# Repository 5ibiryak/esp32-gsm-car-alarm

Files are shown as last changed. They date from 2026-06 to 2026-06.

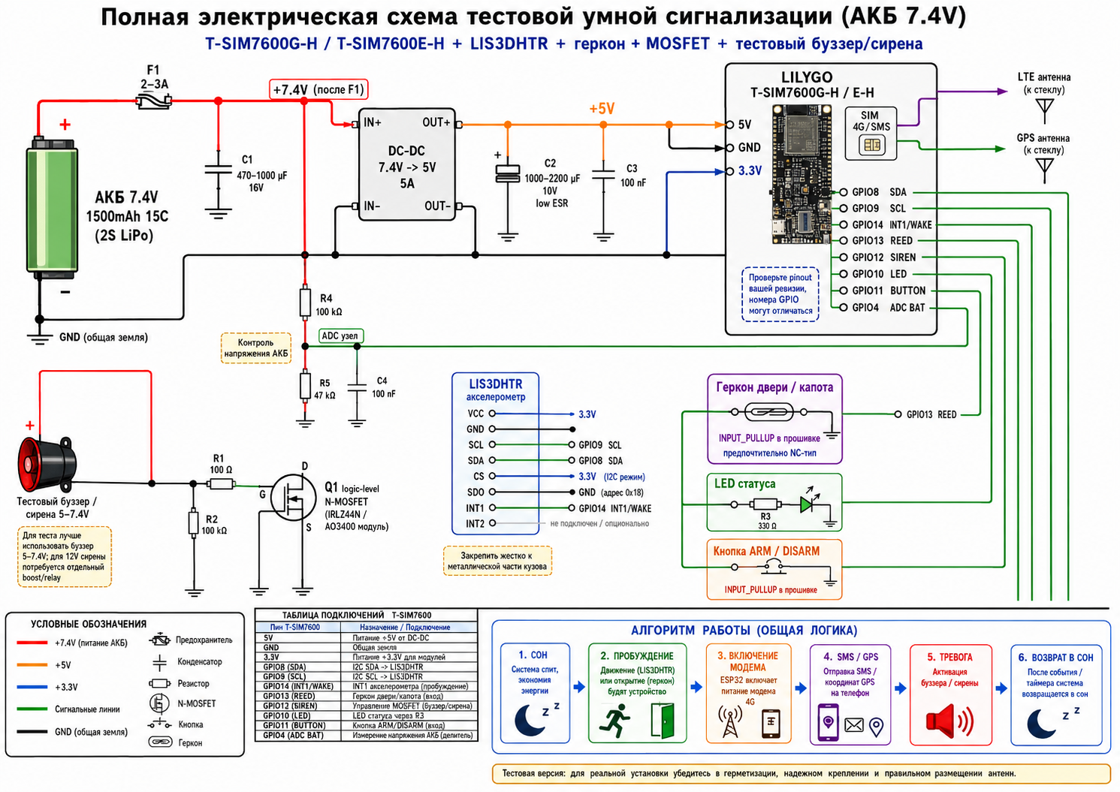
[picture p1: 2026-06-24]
image/ChatGPT Image 24 мая 2026 г., 12_21_52.png

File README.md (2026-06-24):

# ESP32 GSM Car Alarm

Autonomous GSM/GPS car alarm system for Moskvich 412 based on ESP32 and the LILYGO T-SIM7600G-H module.

## Description

This project is an autonomous GSM/GPS car alarm system designed for a Moskvich 412. It is based on an ESP32 board with the LILYGO T-SIM7600G-H module.

The system is installed inside the car and detects shocks, vibration, door/hood opening and other security events. When an alarm is triggered, the device can activate a siren and send SMS notifications to the owner.

The alarm is already installed in the car and is being tested in real conditions.

## Features

* Shock and vibration detection using MPU6050;
* reed switch input for door/hood detection;
* siren control through a MOSFET;
* status LED indicator;
* SMS notifications using SIM7600;
* GPS location support;
* adjustable sensitivity and runtime parameters;
* OTA/web configuration support;
* 3D-printable mounts for the sensor and LED indicator.

## Hardware

Main components:

* LILYGO T-SIM7600G-H / ESP32-WROVER;
* MPU6050 accelerometer;
* SIM7600 GSM/GPS modem;
* reed switch;
* siren;
* MOSFET for siren control;
* external battery;
* 3D-printed enclosure and mounting parts.

## Pinout

| Function | GPIO |
| --- | -----: |
| I2C SDA | GPIO21 |
| I2C SCL | GPIO22 |
| MPU6050 INT | GPIO14 |
| Reed switch | GPIO13 |
| Siren | GPIO32 |
| Status LED | GPIO19 |
| BAT ADC | GPIO35 |
| SIM7600 TX | GPIO27 |
| SIM7600 RX | GPIO26 |
| SIM7600 PWRKEY |  GPIO4 |
| SIM7600 DTR | GPIO25 |

## Project Structure

```text
.
├── include/                 # Header files
├── src/                     # Main firmware source code
├── platformio.ini           # PlatformIO build configuration
├── partitions_ota.csv       # OTA partition table
├── README.md
├── moskvich_alarm_3d.html   # 3D project visualization
├── mpu6050_car_body_mount.stl
├── led_window_holder_5mm.stl
└── images/                  # Wiring diagrams, renders and reference images
```

## Build and Upload

The project is built using PlatformIO.

Build:

```bash
pio run
```

Upload firmware:

```bash
pio run -t upload
```

Serial monitor:

```bash
pio device monitor
```

## 3D Models

The repository includes STL files:

* `mpu6050_car_body_mount.stl` — MPU6050 mount for attaching the sensor to the car body;
* `led_window_holder_5mm.stl` — 5 mm LED holder for placing the status indicator near the window.

## Images and Diagrams

The repository contains wiring diagrams, board reference images and project visualizations.

Recommended structure:

```text
images/
├── wiring-diagram.png
├── 3d-preview.png
└── lilygo-pinout.jpg
```

## Project Status

The project is under active development and real-world testing.

Current status:

* installed in the car;
* basic alarm logic is working;
* SMS notifications are working;
* MPU6050 sensitivity tuning is in progress;
* enclosure, mounting parts and power circuit are being improved.

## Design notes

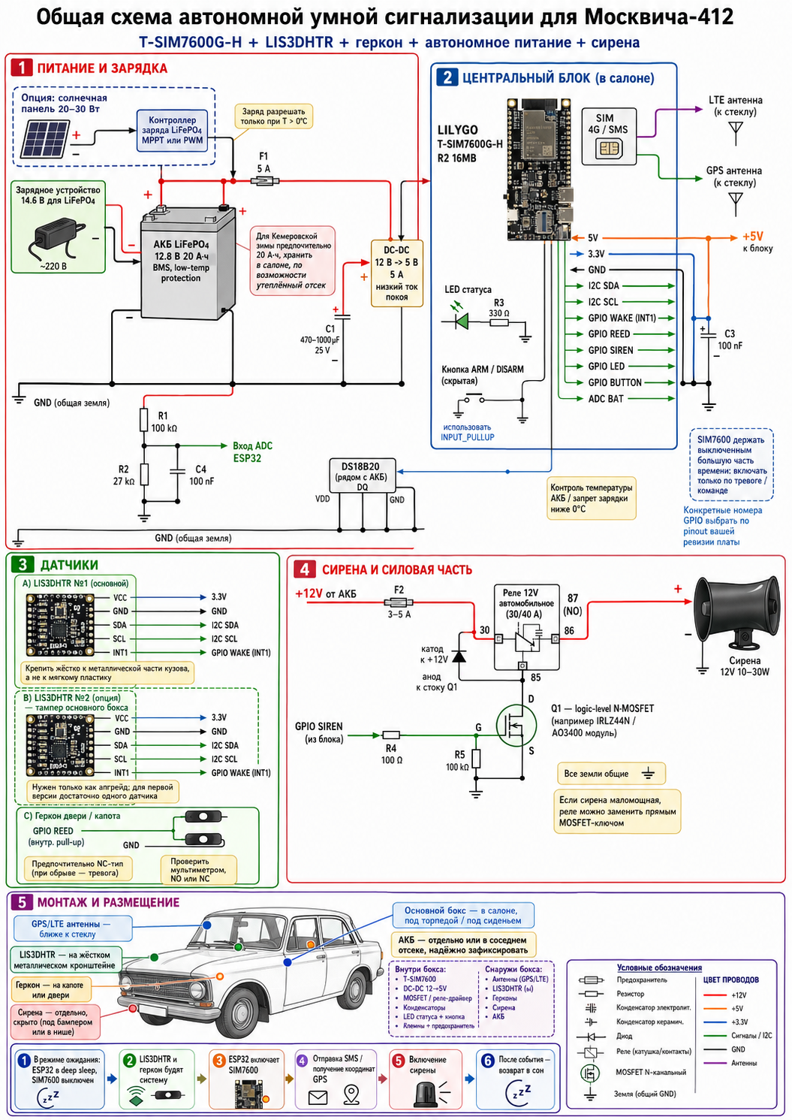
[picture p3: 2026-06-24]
image/Примерная схема сигнализации.png

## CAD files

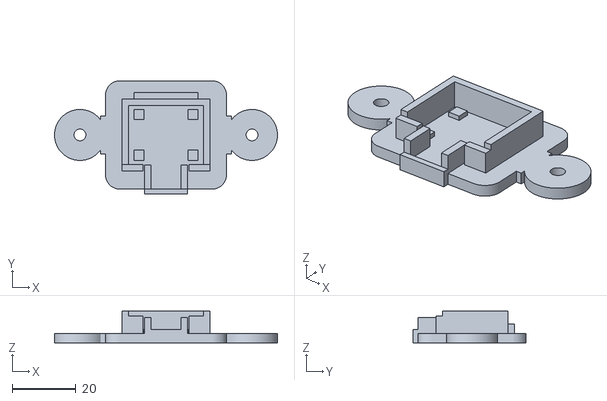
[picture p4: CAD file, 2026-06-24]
3d model/mpu6050_car_body_mount.stl
70.0 x 35.6 x 10.0

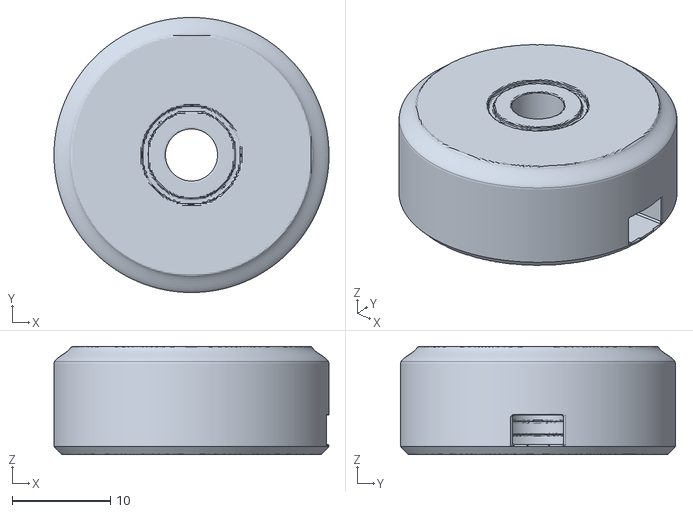
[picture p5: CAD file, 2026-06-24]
3d model/led_window_holder_5mm.stl
28.0 x 28.0 x 11.0

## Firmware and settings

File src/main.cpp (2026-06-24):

#include <Arduino.h>
#include "config.h"

#if WATCHDOG_ENABLED
#include <esp_task_wdt.h>
#endif
#include <esp_system.h>

#include "BatteryMonitor.h"
#include "Accelerometer.h"
#include "ReedSensor.h"
#include "Siren.h"
#include "StatusLed.h"
#include "Button.h"
#include "Modem.h"
#include "RecipientManager.h"
#include "OtaManager.h"
#include "AlarmStateMachine.h"
#include "RuntimeConfig.h"

static BatteryMonitor    battery;
static Accelerometer     accel;
static ReedSensor        reed;
static Siren             siren;
static StatusLed         led;
static Button            button;
static Modem             modem;
static RecipientManager  recipients;
static OtaManager        ota;
static AlarmStateMachine fsm;

static void printBanner() {
    Serial.println();
    Serial.println(F("======================================================"));
    Serial.print  (F("  ")); Serial.print(FW_NAME);
    Serial.print  (F("  v")); Serial.println(FW_VERSION);
    Serial.print  (F("  build: ")); Serial.println(FW_BUILD);
    Serial.println(F("  target: LILYGO T-SIM7600G-H (ESP32-WROVER)"));
    Serial.println(F("======================================================"));
}

static void printPinMap() {
    Serial.println(F("[PINS] --- external peripherals ---"));
    Serial.print(F("  I2C SDA       = GPIO")); Serial.println(PIN_I2C_SDA);
    Serial.print(F("  I2C SCL       = GPIO")); Serial.println(PIN_I2C_SCL);
    Serial.print(F("  ACCEL_INT     = GPIO")); Serial.println(PIN_ACCEL_INT);
    Serial.print(F("  REED          = GPIO")); Serial.println(PIN_REED);
    Serial.print(F("  SIREN         = GPIO")); Serial.println(PIN_SIREN);
    Serial.print(F("  STATUS_LED    = GPIO")); Serial.println(PIN_STATUS_LED);
    Serial.print(F("  BUTTON        = GPIO")); Serial.print(PIN_BUTTON);
    Serial.println(F(" (unused — physical power switch disarms)"));
    Serial.print(F("  BAT_ADC       = GPIO")); Serial.println(PIN_BAT_ADC);

    Serial.println(F("[PINS] --- SIM7600 modem (LILYGO defaults, do not change) ---"));
    Serial.print(F("  MODEM_TX      = GPIO")); Serial.println(MODEM_PIN_TX);
    Serial.print(F("  MODEM_RX      = GPIO")); Serial.println(MODEM_PIN_RX);
    Serial.print(F("  MODEM_PWRKEY  = GPIO")); Serial.println(MODEM_PIN_PWRKEY);
    Serial.print(F("  MODEM_DTR     = GPIO")); Serial.println(MODEM_PIN_DTR);
    Serial.print(F("  MODEM_BAUD    = "));     Serial.println(MODEM_UART_BAUD);
}

#if DEBUG_I2C_LINE_TEST
// Drives GPIO21 / GPIO22 directly so you can verify with a multimeter
// that the signals reach the sensor's SDA / SCL pads.
//
// LOW phase  -> pinMode(OUTPUT_OPEN_DRAIN) + digitalWrite(LOW)  : active pull-down
// RELEASED   -> digitalWrite(HIGH) + pinMode(INPUT_PULLUP)      : ESP32 internal
//               ~45kΩ pull-up plus any module pull-up bring the line to 3.3V
//
// We need INPUT_PULLUP on release because OUTPUT_OPEN_DRAIN with the pin
// driven HIGH still leaves the line floating if no external pull-up is
// fitted — which is what was happening here (lines sat near 0V).
// Loops forever — power-cycle or reset to exit.
static void releaseLine(uint8_t pin) {
    digitalWrite(pin, HIGH);
    pinMode(pin, INPUT_PULLUP);
}
static void pullLineLow(uint8_t pin) {
    pinMode(pin, OUTPUT_OPEN_DRAIN);
    digitalWrite(pin, LOW);
}

static void runI2cLineTest() {
    Serial.println(F("[I2C-LINE] testing GPIO21/GPIO22 physical wiring"));

    releaseLine(21);
    releaseLine(22);

    for (;;) {
        // Phase A: SDA (GPIO21) actively pulled low, SCL released high.
        Serial.println(F("[I2C-LINE] GPIO21 LOW: measure SDA"));
        pullLineLow(21);
        releaseLine(22);
        delay(10000);

        // Phase B: SDA released high, SCL (GPIO22) actively pulled low.
        Serial.println(F("[I2C-LINE] GPIO22 LOW: measure SCL"));
        releaseLine(21);
        pullLineLow(22);
        delay(10000);

        // Phase C: both released to INPUT_PULLUP — both should read ~3.3 V.
        Serial.println(F("[I2C-LINE] RELEASED: both pins INPUT_PULLUP, measure SDA/SCL"));
        releaseLine(21);
        releaseLine(22);
        delay(10000);
    }
}
#endif

static const char* resetReasonName(esp_reset_reason_t r) {
    switch (r) {
        case ESP_RST_POWERON:    return "POWERON";
        case ESP_RST_EXT:        return "EXT";
        case ESP_RST_SW:         return "SW";
        case ESP_RST_PANIC:      return "PANIC";
        case ESP_RST_INT_WDT:    return "INT_WDT";
        case ESP_RST_TASK_WDT:   return "TASK_WDT";
        case ESP_RST_WDT:        return "WDT";
        case ESP_RST_DEEPSLEEP:  return "DEEPSLEEP";
        case ESP_RST_BROWNOUT:   return "BROWNOUT";
        case ESP_RST_SDIO:       return "SDIO";
        default:                 return "UNKNOWN";
    }
}

void setup() {
    Serial.begin(115200);
    delay(200);   // let the host USB enumerate before banner

    const esp_reset_reason_t resetReason = esp_reset_reason();
    Serial.print  (F("[BOOT] reset reason: "));
    Serial.println(resetReasonName(resetReason));
    if (resetReason == ESP_RST_TASK_WDT ||
        resetReason == ESP_RST_INT_WDT  ||
        resetReason == ESP_RST_WDT) {
        Serial.println(F("[BOOT] previous reset was watchdog"));
    }

#if WATCHDOG_ENABLED
    esp_task_wdt_init(WATCHDOG_TIMEOUT_SEC, true);
    esp_task_wdt_add(NULL);
    Serial.print  (F("[WDT] enabled timeout="));
    Serial.print  (WATCHDOG_TIMEOUT_SEC);
    Serial.println(F("s"));
#endif

    Serial.print  (F("[FW] version="));
    Serial.print  (FW_VERSION);
    Serial.print  (F(" build="));
    Serial.print  (FW_BUILD_DATE);
    Serial.print  (F(" "));
    Serial.println(FW_BUILD_TIME);

#if DEBUG_GPIO19_INPUT_TEST
    // Standalone GPIO19 input test. Runs BEFORE any subsystem init so
    // nothing else in firmware can drive the pin. Plain INPUT, no internal
    // pull-up / pull-down — an external jumper to GND or 3V3 chooses the
    // level. Never returns — power-cycle or flash with the flag set to 0
    // to exit.
    Serial.println();
    Serial.println(F("[GPIO19] standalone GPIO19 INPUT read test — no SPI, no LIS3DH"));
    Serial.println(F("[GPIO19] manually tie GPIO19 to GND or 3V3 to verify reads"));
    pinMode(19, INPUT);
    for (;;) {
        Serial.print(F("[GPIO19] GPIO19 read = "));
        Serial.println(digitalRead(19));
        delay(500);
    }
#endif

    printBanner();
    printPinMap();

#if DEBUG_GPIO23_TEST
    // Standalone GPIO23 toggle test. Runs BEFORE any subsystem init so
    // nothing else in firmware can drive the pin. Never returns —
    // power-cycle or flash with DEBUG_GPIO23_TEST=0 to exit.
    Serial.println(F("[GPIO23] standalone GPIO23 toggle test — no SPI, no LIS3DH"));
    pinMode(23, OUTPUT);
    for (;;) {
        digitalWrite(23, HIGH);
        delay(50);   // settle before readback
        Serial.print(F("GPIO23 HIGH, readback = "));
        Serial.println(digitalRead(23));
        delay(3000);

        digitalWrite(23, LOW);
        delay(50);
        Serial.print(F("GPIO23 LOW, readback = "));
        Serial.println(digitalRead(23));
        delay(3000);
    }
#endif

#if DEBUG_I2C_LINE_TEST
    runI2cLineTest();   // never returns — disable the flag to resume normal boot
#endif

    runtimeConfig.begin();

    // Subsystem bring-up.
    battery.begin();
    accel.begin();
    reed.begin();
    siren.begin();
    led.begin();

#if ALARM_HAS_ARM_BUTTON
    button.begin();
#else
    Serial.println(F("[BTN] disabled — physical power switch is used instead"));
#endif

    recipients.begin();
    modem.setRecipientManager(&recipients);
    modem.begin();
    battery.setModem(&modem);
    ota.begin();
    fsm.begin(&accel, &reed, &led, &siren, &modem, &battery, &ota);
    modem.setAlarmFsm(&fsm);
    ota.setAlarmFsm(&fsm);
    ota.setModem(&modem);
    ota.setBattery(&battery);
    ota.setReed(&reed);
    ota.setAccel(&accel);

    Serial.println(F("[BOOT] setup() complete — entering main loop"));
}

static void logStateLine() {
    Serial.print(F("[STATE] state="));   Serial.print(fsm.stateName());
    if (fsm.state() == AlarmStateMachine::ALARM) {
        Serial.print(F(" reason="));     Serial.print(fsm.triggerReasonName());
    }
    Serial.print(F(" reed="));           Serial.print(reed.isOpen() ? F("OPEN") : F("CLOSED"));
    Serial.print(F(" motion="));         Serial.print(accel.isMotionDetected() ? 1 : 0);
    Serial.print(F(" mag="));            Serial.print(accel.getMagnitude(), 3);
    Serial.print(F(" delta="));          Serial.print(accel.getDeltaG(), 3);

    if (battery.hasValidMeasurement()) {
        Serial.print(F(" battery="));
        Serial.print(battery.getVoltageV(), 2);
        Serial.print(F("V current="));
        Serial.print((long)lroundf(battery.getCurrentA() * 1000.0f));
        Serial.print(F("mA est="));
        if (battery.hasValidEstimate()) {
            Serial.print(battery.getEstimatedRemainingDays(), 1);
            Serial.println(F("d"));
        } else {
            Serial.println(F("UNKNOWN"));
        }
    } else {
        Serial.println(F(" battery=UNKNOWN"));
    }
}

static void logHealthLine() {
    Serial.print  (F("[HEALTH] modem="));
    Serial.print  (modem.isAvailable() ? F("OK") : F("DOWN"));
    Serial.print  (F(" registered="));
    Serial.print  (modem.isNetworkRegistered() ? F("yes") : F("no"));
    Serial.print  (F(" atFail="));
    Serial.print  (modem.getConsecutiveAtFailures());
    Serial.print  (F(" smsQ="));
    Serial.print  (modem.pendingSmsCount());
    Serial.print  (F(" gps="));
    Serial.println(modem.gnssStarted() ? F("active") : F("idle"));
}

void loop() {
    battery.update();
    accel.update();
    reed.update();
    fsm.update();
    led.update();
    siren.update();
    modem.update();
    ota.update();

#if WATCHDOG_ENABLED
    esp_task_wdt_reset();
#endif

    static uint32_t lastStateLogMs  = 0;
    static uint32_t lastHealthLogMs = 0;
    const uint32_t now = millis();
    if ((now - lastStateLogMs) >= runtimeConfig.stateLogIntervalMs()) {
        lastStateLogMs = now;
        logStateLine();
    }
    if ((now - lastHealthLogMs) >= DEBUG_HEALTH_PERIOD_MS) {
        lastHealthLogMs = now;
        logHealthLine();
    }
}

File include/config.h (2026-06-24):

#pragma once

// =====================================================================
// Smart car alarm firmware — central configuration
// Board: LILYGO T-SIM7600G-H / T-SIM7600E-H (ESP32-WROVER + SIM7600)
// =====================================================================

#include <Arduino.h>
#include <driver/adc.h>   // adc1_channel_t, adc_atten_t, adc_bits_width_t (ESP-IDF v4)

// ---------------------------------------------------------------------
// Firmware version & identity
// ---------------------------------------------------------------------
#define FW_NAME       "MoskvichAlarm"
#define FW_VERSION    "0.1.0-webcfg"
#define FW_BUILD_DATE __DATE__
#define FW_BUILD_TIME __TIME__
#define FW_BUILD      __DATE__ " " __TIME__

// ---------------------------------------------------------------------
// Debug flags — set to 1 to enable verbose Serial logs per subsystem
// ---------------------------------------------------------------------
#define DEBUG_BATTERY 1
#define DEBUG_ACCEL   1
#define DEBUG_REED    1
#define DEBUG_MODEM   1
#define DEBUG_ALARM   1
#define DEBUG_SIREN   1
#define DEBUG_BUTTON  1
#define DEBUG_LED     1

// MPU verbose polling. When 1, every ACCEL_POLL_PERIOD_MS update prints
// the raw + g + magnitude + delta values. When 0, those lines are silenced
// but the values are still computed and exposed via the Accelerometer
// getters (used by the periodic [STATE] log). Motion-edge events still
// print regardless of this flag.
#define DEBUG_MPU_VERBOSE  0

// ---- Local alarm core flags ----
// ALARM_HAS_ARM_BUTTON = 0: no GPIO arm/disarm input. The whole device is
// powered through a physical switch on the DC-DC input; cutting that
// switch is the only way to disarm. Button.cpp/h stay in the tree but
// are never initialized or polled.
#define ALARM_HAS_ARM_BUTTON            0

// When 1, BatteryMonitor CRITICAL state must NOT block alarm logic. The
// battery divider is not wired yet; the monitor still runs and prints,
// but the FSM ignores its result.
#define DEBUG_IGNORE_BATTERY_CRITICAL   1

// When 1, the siren is driven with a low-duty-cycle "safe" pulse pattern
// (200 ms ON / 800 ms OFF) and an optional short confirmation beep at the
// start of ARMING_DELAY. Set to 0 for a continuous-on siren later.
#define DEBUG_SIREN_SAFE_MODE           1

// Phase 3 SPI / single-GPIO diagnostics — retired. These flags must remain
// at 0; the firmware no longer contains SPI or standalone GPIO test code.
#define ACCEL_USE_SPI_DIAG       0
#define DEBUG_SPI_BITBANG_TEST   0
#define DEBUG_GPIO23_TEST        0
#define DEBUG_GPIO19_INPUT_TEST  0

// =====================================================================
// PIN MAP
// =====================================================================
// ESP32 pins to AVOID for external peripherals on this board:
//   GPIO0,2,15  — boot strapping
//   GPIO5,12    — boot strapping / can hang boot if pulled wrong
//   GPIO16,17   — used by PSRAM on ESP32-WROVER (do not touch)
//
// =====================================================================
// !!! FORBIDDEN MODEM PINS — hard-wired to SIM7600 on the LILYGO PCB.
// !!! DO NOT use these for any external peripheral.
// =====================================================================
//   GPIO27 = MODEM_TX      (ESP32 -> SIM7600 RX)
//   GPIO26 = MODEM_RX      (SIM7600 TX -> ESP32)
//   GPIO4  = MODEM_PWRKEY  (~1s LOW pulse powers the modem on)
//   GPIO25 = MODEM_DTR     (sleep / wake control)
// =====================================================================

// ---- I2C bus (MPU-6050 accelerometer) ----
// ESP32 default I2C pins. Free on LILYGO T-SIM7600G-H.
#define PIN_I2C_SDA      21
#define PIN_I2C_SCL      22

// ---- Accelerometer interrupt ----
#define PIN_ACCEL_INT    14   // INT from MPU-6050 (disconnected for Phase 3)

// ---- Reed switch ----
#define PIN_REED         13   // INPUT_PULLUP, GND on event (NC preferred)

// ---- Siren / buzzer via MOSFET ----
// External 100kΩ gate pulldown holds Q1 OFF during boot/reset.
#define PIN_SIREN        32

// ---- Status LED ----
// GPIO19 is a plain digital output, fine for an LED.
#define PIN_STATUS_LED   19

// ---- ARM/DISARM button ----
// GPIO33 is RTC-capable (RTC_GPIO8) — usable as an EXT0 deep-sleep wake
// source in Phase 11.
#define PIN_BUTTON       33

// ---- Battery voltage ADC ----
// Input-only ADC1_CH7. Works fine with the 100k/47k divider.
#define PIN_BAT_ADC      35
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

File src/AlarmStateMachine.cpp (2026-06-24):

#include "AlarmStateMachine.h"
#include "Accelerometer.h"
#include "ReedSensor.h"
#include "StatusLed.h"
#include "Siren.h"
#include "Modem.h"
#include "BatteryMonitor.h"
#include "RecipientManager.h"
#include "OtaManager.h"
#include "RuntimeConfig.h"
#include "config.h"

// ----- Name tables ----------------------------------------------------------

const char* AlarmStateMachine::stateName(State s) {
    switch (s) {
        case DISARMED:     return "DISARMED";
        case ARMING_DELAY: return "ARMING_DELAY";
        case ARMED:        return "ARMED";
        case ALARM:        return "ALARM";
    }
    return "?";
}

const char* AlarmStateMachine::triggerReasonName(AlarmTriggerReason r) {
    switch (r) {
        case TRIGGER_NONE:      return "none";
        case TRIGGER_MOTION:    return "MOTION";
        case TRIGGER_REED_OPEN: return "REED_OPEN";
        case TRIGGER_IMPACT:    return "IMPACT";
        case TRIGGER_TILT:      return "TILT";
        case TRIGGER_MOVE:      return "MOVE";
    }
    return "?";
}

const char* AlarmStateMachine::commandName(RemoteCommand c) {
    switch (c) {
        case RemoteCommand::STATUS:         return "STATUS";
        case RemoteCommand::ARM:            return "ARM";
        case RemoteCommand::DISARM:         return "DISARM";
        case RemoteCommand::SILENT_DISARM:  return "SILENT_DISARM";
        case RemoteCommand::SIREN_TEST:     return "SIREN_TEST";
        case RemoteCommand::MODEM_STATUS:   return "MODEM_STATUS";
        case RemoteCommand::BATTERY_STATUS: return "BATTERY_STATUS";
        case RemoteCommand::GPS_LOCATION:   return "GPS_LOCATION";
        case RemoteCommand::OTA_UPDATE:     return "OTA_UPDATE";
        case RemoteCommand::HELP:           return "HELP";
    }
    return "?";
}

bool AlarmStateMachine::parseRemoteCommand(const String& body, RemoteCommand& out) {
    String t = body;
    t.trim();
    if (t.length() == 0) return false;
    for (size_t i = 0; i < t.length(); ++i) {
        if (!isDigit(t.charAt(i))) return false;
    }
    const int v = t.toInt();
    if (v < 0 || v > 9) return false;
    out = (RemoteCommand)v;
    return true;
}

// ----- Setup ----------------------------------------------------------------

void AlarmStateMachine::begin(Accelerometer* accel, ReedSensor* reed,
                              StatusLed* led, Siren* siren,
                              Modem* modem, BatteryMonitor* battery,
                              OtaManager* ota) {
    _accel   = accel;
    _reed    = reed;
    _led     = led;
    _siren   = siren;
    _modem   = modem;
    _battery = battery;
    _ota     = ota;

    // Automatic arming on boot (per current power-switch design).
    enterArmingDelay(SIREN_CONFIRM_ON_BOOT_ARM != 0);
}

// ----- State entries --------------------------------------------------------

void AlarmStateMachine::enterDisarmed(bool playConfirm) {
    const State prev    = _state;
    _state              = DISARMED;
    _stateEnteredMs     = millis();
    _triggerReason      = TRIGGER_NONE;
    _alarmBannerPrinted = false;
    _sirenMuted         = false;

    if (_led)   _led->setMode(StatusLed::DISARMED);
    if (_modem) _modem->resetAlarmSmsLatch();

    // Always cancel any current siren activity first; then play disarm
    // confirmation beeps if the caller asked for them.
    if (_siren) _siren->off();
    if (playConfirm && _siren) _siren->confirmDisarm();

#if DEBUG_ALARM
    if (prev == ALARM) {
        Serial.println(F("[FSM] ALARM -> DISARMED"));
    } else {
        Serial.println(F("[FSM] -> DISARMED"));
    }
#else
    (void)prev;
#endif
}

void AlarmStateMachine::enterArmingDelay(bool playConfirm) {
    _state              = ARMING_DELAY;
    _stateEnteredMs     = millis();
    _lastArmingPrintMs  = _stateEnteredMs;
    _triggerReason      = TRIGGER_NONE;
    _sirenMuted         = false;

    if (_led)   _led->setMode(StatusLed::ARMING_DELAY);
    if (_modem) _modem->resetAlarmSmsLatch();   // new session can SMS again
    // Kick the smart motion detector into its calibration window so it
    // can build a fresh baseline before ARMED protection kicks in.
    if (_accel) _accel->resetAndCalibrate();

    // Cancel any prior siren state and optionally start the arm confirm
    // beep. Siren manages its own timing — no FSM-side beep tracking.
    if (_siren) _siren->off();
    if (playConfirm && _siren) _siren->confirmArm();

#if DEBUG_ALARM
    Serial.println(F("[FSM] -> ARMING_DELAY"));
    Serial.print  (F("[FSM] ARMING_DELAY duration = "));
    Serial.print  (runtimeConfig.armingDelayMs());
    Serial.println(F(" ms"));
#endif
}

void AlarmStateMachine::enterArmed() {
    _state          = ARMED;
    _stateEnteredMs = millis();

    if (_siren) _siren->off();
    if (_led)   _led->setMode(StatusLed::ARMED);
    // Start the smart detector's early-stabilization window.
    if (_accel) _accel->markArmed();

#if DEBUG_ALARM
    Serial.println(F("[FSM] ARMING_DELAY -> ARMED"));
    Serial.println(F("[FSM] ARMED sensor grace period"));
#endif
}

void AlarmStateMachine::enterAlarm(AlarmTriggerReason reason) {
    _state              = ALARM;
    _triggerReason      = reason;
    _stateEnteredMs     = millis();
    _alarmBannerPrinted = false;
    _sirenMuted         = false;

    if (_led)   _led->setMode(StatusLed::ALARM);
    if (_siren) _siren->alarmPattern();

#if DEBUG_ALARM
    Serial.print  (F("[FSM] ARMED -> ALARM reason="));
    Serial.println(triggerReasonName(reason));
#endif

#if SMS_ALERT_ENABLED
    if (_modem) {
        _modem->queueAlarmSms(triggerReasonName(reason));
    }
#endif
}

// ----- update ---------------------------------------------------------------
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

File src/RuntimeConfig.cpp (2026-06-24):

#include "RuntimeConfig.h"

#include <Preferences.h>
#include <math.h>

// Single global instance — declared `extern` in the header so subsystems
// can reach it without plumbing a pointer through every constructor.
RuntimeConfig runtimeConfig;

// Out-of-line definition of the static name table.
const RuntimeConfig::FieldNamesType RuntimeConfig::FieldNames;

static constexpr const char* kNvsNamespace = "runtime_cfg";

namespace {

// Validation helpers.
bool inRange(float v, float lo, float hi) {
    return isfinite(v) && v >= lo && v <= hi;
}
bool inRangeL(long v, long lo, long hi) {
    return v >= lo && v <= hi;
}

}  // namespace

void RuntimeConfig::logInvalid(const char* field) const {
    Serial.print  (F("[CFG] invalid value for "));
    Serial.print  (field);
    Serial.println(F(", using default"));
}

// ----- Defaults / load / save -----------------------------------------------

void RuntimeConfig::applyDefaults() {
    _motionDeltaThresholdG            = ACCEL_MOTION_DELTA_G;
    _motionConfirmSamples             = 2;
    _motionCooldownMs                 = 3000UL;

    _armingDelayMs                    = ALARM_ARMING_DELAY_MS;
    _armedSensorGraceMs               = ALARM_ARMED_SENSOR_GRACE_MS;

    _sirenAlarmContinuousMs           = SIREN_ALARM_CONTINUOUS_MS;
    _sirenAfterTimeoutReminderEnabled = SIREN_AFTER_TIMEOUT_REMINDER_ENABLED != 0;
    _sirenReminderOnMs                = SIREN_REMINDER_ON_MS;
    _sirenReminderOffMs               = SIREN_REMINDER_OFF_MS;

    _lowBatterySmsEnabled             = LOW_BATTERY_SMS_ENABLED != 0;
    _batteryCapacityAh                = BATTERY_CAPACITY_AH;
    _batteryWarnVoltage               = BAT_VOLTAGE_WARN;
    _batteryCriticalVoltage           = BAT_VOLTAGE_CRITICAL;
    _batteryShutdownVoltage           = BAT_VOLTAGE_SHUTDOWN;
    _lowBatteryReserveDays            = LOW_BATTERY_RESERVE_DAYS;
    _lowBatterySmsRepeatHours         = (uint16_t)(LOW_BATTERY_SMS_REPEAT_MS / 3600000UL);
    if (_lowBatterySmsRepeatHours == 0) _lowBatterySmsRepeatHours = 24;

    _stateLogIntervalMs               = STATE_LOG_PERIOD_MS;
    _inaRawLogIntervalMs              = 10000UL;

    _otaActiveWindowMs                = OTA_ACTIVE_WINDOW_MS;

    _smartMotionEnabled       = true;
    _motionCalibrationMs      = 30000UL;
    _motionBaselineAlphaQuiet = 0.002f;
    _impactThresholdG         = 0.080f;
    _impactConfirmWindowMs    = 800UL;
    _impactMinPeaks           = 1;
    _tiltThresholdDeg         = 4.0f;
    _tiltConfirmMs            = 3000UL;
    _moveRmsThresholdG        = 0.020f;
    _moveConfirmMs            = 5000UL;
    _moveMinActivePercent     = 40;
    _motionEarlyWindowMs      = 600000UL;
    _motionEarlyMultiplier    = 1.5f;
}

void RuntimeConfig::begin() {
    Serial.println(F("[CFG] loading runtime config"));
    applyDefaults();
    if (loadFromNvs()) {
        Serial.println(F("[CFG] loaded from NVS"));
    } else {
        Serial.println(F("[CFG] using defaults"));
    }
}

bool RuntimeConfig::loadFromNvs() {
    Preferences p;
    if (!p.begin(kNvsNamespace, /*readOnly*/true)) return false;
    // Sentinel key — if absent, no saved config yet.
    if (!p.isKey("v")) {
        p.end();
        return false;
    }

    // Helper macros: read; if value falls outside valid range, log and
    // keep the default already in place. `name` is the bare field token
    // (e.g. motionDeltaThresholdG). #name turns it into the NVS key
    // string; _##name names the private member variable. Using the bare
    // token directly would resolve to the same-named getter method —
    // that was the original compile failure.
#define LOAD_FLOAT(name, lo, hi)                              \
    do {                                                      \
        const char* key = #name;                              \
        if (p.isKey(key)) {                                   \
            const float v = p.getFloat(key, NAN);             \
            if (inRange(v, lo, hi)) _##name = v;              \
            else                    logInvalid(key);          \
        }                                                     \
    } while (0)

#define LOAD_U32(name, lo, hi)                                \
    do {                                                      \
        const char* key = #name;                              \
        if (p.isKey(key)) {                                   \
            const long v = (long)p.getULong(key, 0);          \
            if (inRangeL(v, (long)(lo), (long)(hi))) _##name = (uint32_t)v; \
            else                                     logInvalid(key); \
        }                                                     \
    } while (0)
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
